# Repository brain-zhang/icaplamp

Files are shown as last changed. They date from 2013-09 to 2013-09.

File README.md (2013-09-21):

icaplamp
========

信息化矿灯

-------------------------------------------
这是朋友提议的一个想法。想要对传统的矿灯做些增强，实现考勤+信息接收+井下定位的功能;
根据这个想法做了个原型，实现了通信的功能(软硬件),定位及考勤功能开发了一个雏形。

    考勤:现实中矿上的考勤方式五花八门，从传统的科室登记，早班专人登记，取灯登记到人脸识别，虹膜识别等等，
    效果都不尽人意.....占用精力，代打卡也不能完全防止，机器识别精度差......

    井下电话:固话及小灵通通信方式倒是很可靠的，只是还不能人手一部。一般每个科室只能配几个。

    井下定位:只能说现有的所有井下定位都不靠谱，RFID定位方式不能适应井下复杂的环境，可靠性太低。

    矿灯是下井必备品，如果矿灯能兼具考勤+通信+定位的功能就比较方便了。
    我们希望通过在矿灯头部设计芯片，加挂贴片无线模块及LED显示屏的方式，实现这些功能。

    这种设计的可靠性，精度及实用性都有待检验，试做的时候碰到了许多问题，
    电池容量，AP功率，接收范围，LED体积，成本......但毕竟是一种思路。

    现在再看看，有些问题已经可以解决了，出现了更轻型更大容量的锂电，更低功耗的贴片天线，
    市面上也有了一些同类产品，但不知道效果如何；但解决成本及可靠性的问题，可能还要等很长时间......

    还有一些根本上的缺陷，功能太杂，很难简单操作，AP无线定位的精度太低，
    另外商业上看这种产品的亮点也不多，最后这种产品要想做成熟的话开发工作浩大......

    如果说有什么收获，可能就是学会了从电路设计,画PCP板子到出板子的一系列过程，
    知道了常用电子原件的价格，熟悉了MSP430的特性.....

    放在这里仅仅是记录曾经一段时间的工作吧。
    如果有人有兴趣翻一下的话，推荐你看下PCB的设计及keil的C程序，我认为这部分写得很清晰，对初学者有些价值。

-------------------------------------------
原理图

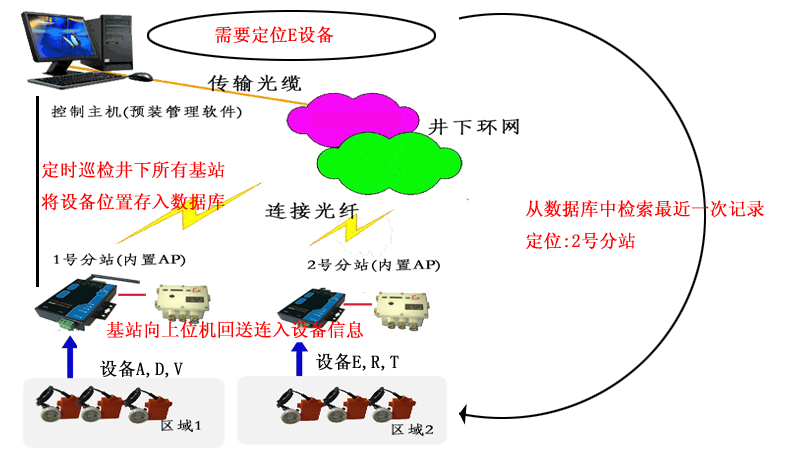
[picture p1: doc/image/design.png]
设计图


-------------------------------------------
电路图

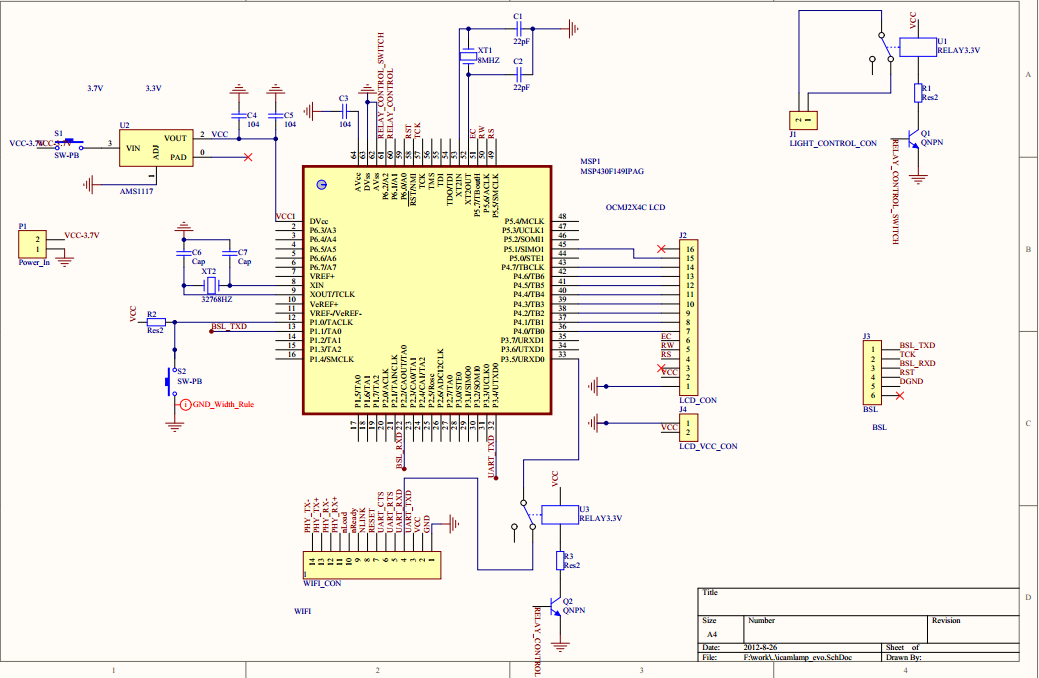
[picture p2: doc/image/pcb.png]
原理图

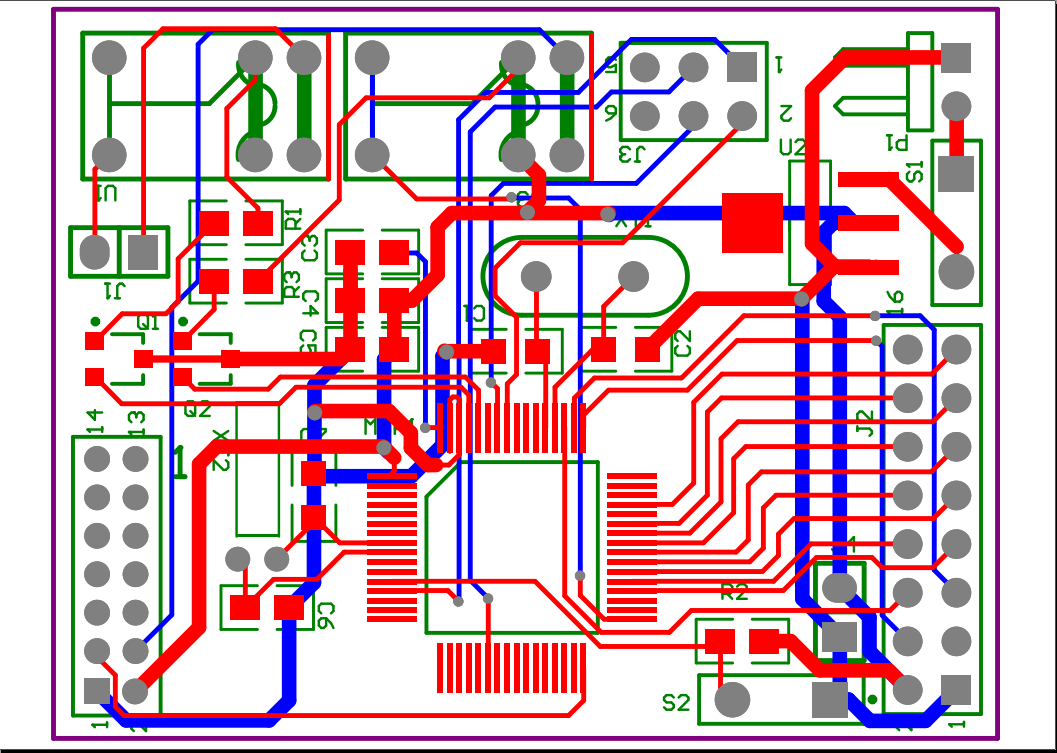
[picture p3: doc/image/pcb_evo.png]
布线图


-------------------------------------------
Resource

    |-- 3part                              第三方元件库
    |-- doc                                设计文档
    |   `-- image
    |-- hardware
    |   |-- PCBlib                         protel设计图
    |   |   `-- History
    |   |-- pcb
    |   `-- source                         keil MSP430程序
    |       |-- Debug
    |       |   |-- Exe
    |       |   |-- List
    |       |   `-- Obj
    |       `-- settings
    |-- software                           vs2010 Demo
    |   `-- IcapLamp
    |       |-- 3rddll
    |       |-- 3rdinclude
    |       |   |-- libssh2
    |       |   `-- openssl
    |       |-- 3rdlib
    |       |-- IcapLamp
    |       |   |-- CustomUtil
    |       |   |-- libssh2
    |       |   `-- res
    |       |-- IcapLampbase
    |       |   `-- IcapLampbase
    |       |       `-- Release
    |       |-- Release
    |       |-- ini
    |       `-- setup
    `-- test

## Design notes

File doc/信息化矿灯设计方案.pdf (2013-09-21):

# 信息化矿灯设计方案

## 一、功能

## 信息接收系统

通过在矿灯上加装信息化模块来接收无线基站的信号并且通过液晶屏幕显示，调度室可

以通过管理软件选择给某个工人单发信息或者给所有工人群发信息，工人的矿灯接收到信息

后头灯会有节奏的闪烁，提示有新信息，当工人阅读后按一下确认按键头灯停止闪烁。

## 人员定位系统

通过矿灯的无线接收模块，井下基站，配合上位机软件，实现人员定位功能：

A. 井上可实时显示基站覆盖范围内的所有矿灯设备
B. 井上可实时显示矿灯设备的井下位置
C. 井上可查询所有下井矿灯设备的位置移动历史记录，并可报表输出

## 二、系统结构

整个系统由无线基站、隔爆兼本安不间断电源、WIFI 模块、核心控制板、液晶屏、矿灯

等部分组成。

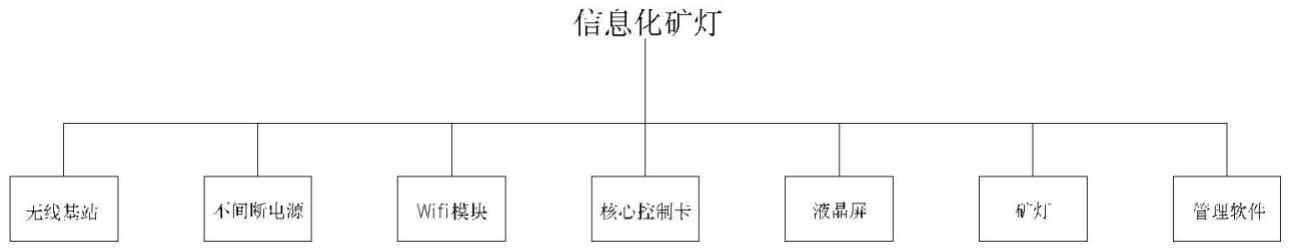
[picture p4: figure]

系统结构图

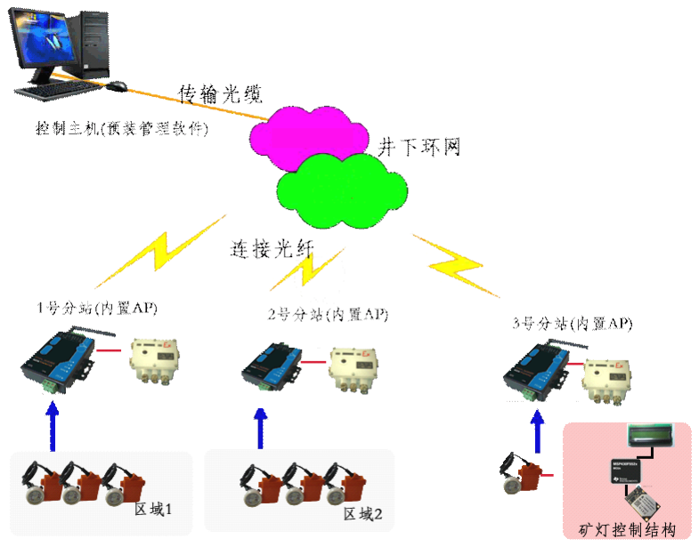
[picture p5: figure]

系统整体示意图

## 三、系统实现

信息接收及人员定位系统，主要依赖上位机软件及矿灯核心控制卡模块 PLC 程序配合完

成。

## 信息接收系统

矿灯设备通过基站接入环网后，WIFI 模块实现了串口设备的网络透明接入，因此可直接

利用 TCP/IP 实现网络通信模型。

核心控制卡 PLC 实现：

设定设备唯一标识(IP 地址)，响应上位机巡检指令

循环检测串口，接收上位机发送的消息，并显示在液晶屏上。

上位机软件实现：

巡检所有井下矿灯设备，并通过 IP 地址确定设备位置，进行如下操作：

1. 给某个工人单发信息
2. 给某组工人群发信息(所有设备群发可视为并入一组)

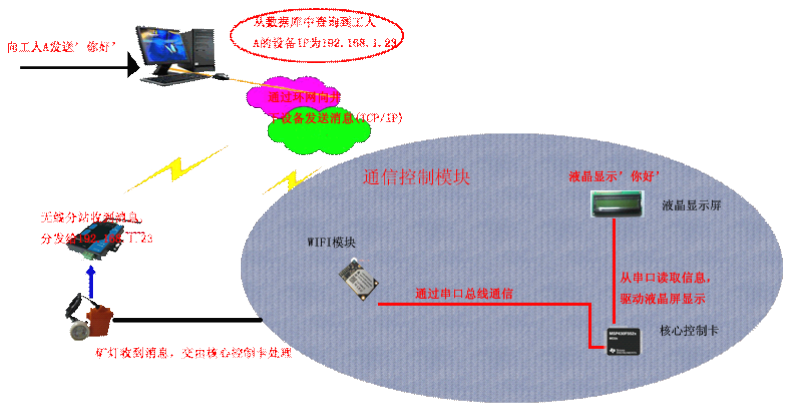
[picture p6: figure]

信息接收流程图

## 人员定位系统

矿灯设备接入井下环网后，可通过巡检每个基站的在线设备 IP 实现人员定位。

上位机软件实现：

1. 定时巡检井下基站(可设置间隔时间，建议 5-10 秒)，检测此基站范围内的所有设

备(通过 IP 地址识别)，并存入数据库。

2. 实时显示所有井下设备的位置信息。
3. 从数据库中查询某设备指定时间的位置记录。
4. 人员定位精度依赖基站的信号覆盖范围，大概 500 米误差。
5. 人员离开基站覆盖范围后，可查询此人员最近一次位置记录点。

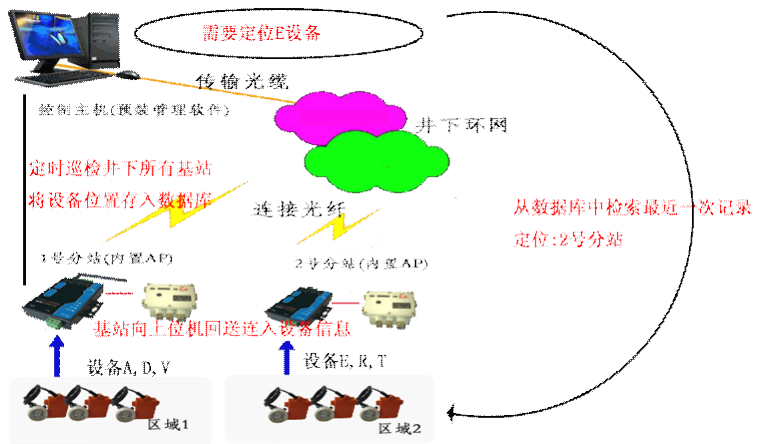
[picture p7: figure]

人员定位系统示意图

## 四、设备技术参数

## 1. 无线基站

无线基站的主要部件是大功率无线 AP，可视范围内覆盖范围可达 500 米。

处理器 | Atheros | MIPS | 24KC, | 400MHz
内存 | 64MB | SDRAM, | 8MB | Flash
网络接口 | 2 X 10/100 BASE-TX (Cat. 5, RJ-45) Ethernet Interface
天线接口 | 2x | RPSMA | (Waterproof)
电源 | 24V, | 1A | POE | Supply | Included
工作温度 | -30C | to | 75C
工作湿度 | 5 | to | 95% | Condensing
发射功率 | 650mW

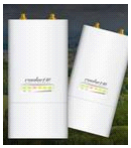
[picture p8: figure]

大功率无线 AP

此外，无线基站内还有矿用光电一体交换机，安装到现场后通过光纤将各基站连接到一

起。

## 2. 矿用隔爆兼本安不间断电源

采用隔爆兼本安不间断电源，正常情况下采用照明线路供电，井下停电时，自动切换到

蓄电池供电模式，保证系统的正常运行，提高系统可靠性。

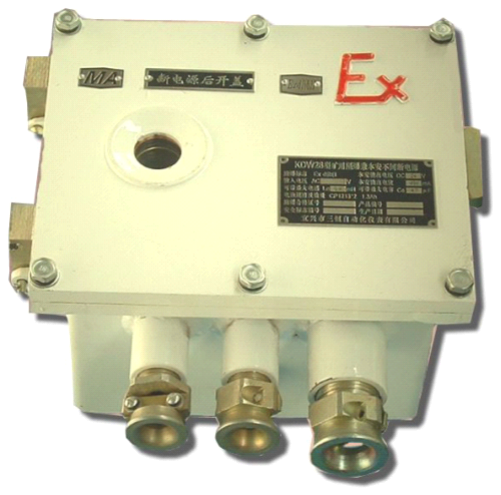
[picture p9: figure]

隔爆兼本安不间断电源

输入电压 | AC127V/380V/660V
工作温度 | -25C | to | 60C
工作时间 | ≥2小时(在额定电流时)
充电方式 | 内部浮充
标称输出电压 | DC | 18V
额定输出电流 | 250mA
最大短路电流 | ≤100mA

### 3. WIFI 模块

选用嵌入式 wifi 转串口模块，接收上位机的消息信号(标准 TCP/IP 协议传输)，转换为串

口数据通信，供核心控制卡处理。

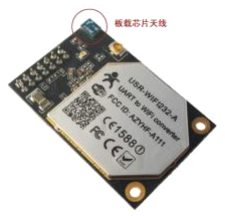
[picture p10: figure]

WIFI 转串口模块 内置天线

## 4. 核心控制卡

采用单片机(MSP430)定制开发，接收串口数据，显示到液晶屏上。

特点：

a. 处理能力强
b. 超低功耗
c. 片内资源丰富
无线标准 | 802.11n
串口命令 | AT+命令结构
数据接口 | URAT、以太网、GPIOs
天线 | 内置板载天线
电源 | 3.3v | 170mA-300mA
工作温度 | -10C | to | 70C
尺寸 | 30 | X | 45 | X | 8 | (mm)
接收灵敏度 | 802.11n:-71dbm

d. 方便高效的开发环境

核心控制卡集成了 wifi 模块，液晶屏及 LED 警示灯，与上位机通过无线网络进行消息传

递，是整套系统井下部分的核心。

## 5. 液晶屏

系统采用 1602 字符型液晶显示，具有功耗低，显示文字锐利，体积小，重量轻的优点。

特性：

a. +5V 电压，对比度可调
b. 内含复位电路
c. 提供各种控制命令,如：清屏、字符闪烁、光标闪烁、显示移位等多种功能
d. 有 80 字节显示数据存储器 DDRAM
e. 内建有 192 个 5X7 点阵的字型的字符发生器 CGROM
f. 8 个可由用户自定义的 5X7 的字符发生器 CGRAM

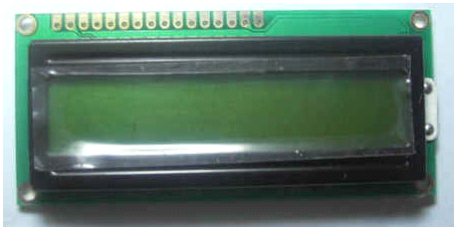
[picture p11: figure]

1602 字符型液晶实物图

## 6. 矿灯

改造模具，在原有产品基础上进行集成。

## 7. 管理软件

井上部分提供控制软件。功能描述如下：

a) 信息接收系统

1. 向井下矿灯设备发送消息
2. 向某一区域矿灯设备发送消息
3. 巡检某一区域(或全体)在线矿灯设备
b) 人员定位系统
4. 实时显示基站覆盖范围内的所有矿灯设备
5. 实时显示所有矿灯设备的井下位置
6. 查询某一基站范围内的矿灯设备历史记录，并可报表输出
7. 查询下井矿灯设备的位置移动历史记录，并可报表输出

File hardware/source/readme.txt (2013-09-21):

2012-08-15
加入了消息存储的底层函数支持。
2012-08-19
基本功能完成，还有按键处理待修改。

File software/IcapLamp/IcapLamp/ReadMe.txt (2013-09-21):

================================================================================
MICROSOFT 基础类库: IcapLamp 项目概述
===============================================================================

应用程序向导已为您创建了这个 IcapLamp 应用程序。此应用程序不仅演示 Microsoft 基础类的基本使用方法，还可作为您编写应用程序的起点。

本文件概要介绍组成 IcapLamp 应用程序的每个文件的内容。

IcapLamp.vcxproj
这是使用应用程序向导生成的 VC++ 项目的主项目文件。 
它包含生成该文件的 Visual C++ 的版本信息，以及有关使用应用程序向导选择的平台、配置和项目功能的信息。

IcapLamp.vcxproj.filters
    这是使用“应用程序向导”生成的 VC++ 项目筛选器文件。
    它包含有关项目文件与筛选器之间的关联信息。在 IDE 中，通过这种关联，在特定节点下以分组形式显示具有相似扩展名的文件。例如，“.cpp”文件与“源文件”筛选器关联。

IcapLamp.h
这是应用程序的主要头文件。它包括其他项目特定的头文件(包括 Resource.h)，并声明 CIcapLampApp 应用程序类。

IcapLamp.cpp
这是包含应用程序类 CIcapLampApp 的主要应用程序源文件。

IcapLamp.rc
这是程序使用的所有 Microsoft Windows 资源的列表。它包括 RES 子目录中存储的图标、位图和光标。此文件可以直接在 Microsoft Visual C++ 中进行编辑。项目资源位于 2052 中。

res\IcapLamp.ico
这是用作应用程序图标的图标文件。此图标包括在主要资源文件 IcapLamp.rc 中。

res\IcapLamp.rc2
此文件包含不在 Microsoft Visual C++ 中进行编辑的资源。您应该将不可由资源编辑器编辑的所有资源放在此文件中。

/////////////////////////////////////////////////////////////////////////////

对于主框架窗口:
项目包含标准 MFC 界面。

MainFrm.h, MainFrm.cpp
这些文件包含框架类 CMainFrame，该类派生自
CFrameWnd 并控制所有 SDI 框架功能。

/////////////////////////////////////////////////////////////////////////////

应用程序向导创建一个文档类型和一个视图:

DirectionMonitorDoc.h，IcapLampDoc.cpp - 文档
这些文件包含 CDirectionMonitorDoc 类。编辑这些文件可以添加特殊文档数据并可实现文件保存和加载(通过 CDirectionMonitorDoc::Serialize)。

DirectionMonitorFormView.h，IcapLampView.cpp - 文档的视图
这些文件包含 CDirectionMonitorFormView 类。
CDirectionMonitorFormView 对象用于查看 CDirectionMonitorDoc 对象。

/////////////////////////////////////////////////////////////////////////////

其他功能:

ActiveX 控件
应用程序包括对使用 ActiveX 控件的支持。

打印及打印预览支持
应用程序向导已通过从 MFC 库调用 CView 类中的成员函数，生成了用于处理打印、打印设置和打印预览命令的代码。

Windows Sockets
应用程序支持通过 TCP/IP 网络建立通信。

/////////////////////////////////////////////////////////////////////////////

其他标准文件:

StdAfx.h，StdAfx.cpp
这些文件用于生成名为 IcapLamp.pch 的预编译头 (PCH) 文件和名为 StdAfx.obj 的预编译类型文件。

Resource.h
这是标准头文件，它定义新的资源 ID。
Microsoft Visual C++ 读取并更新此文件。

IcapLamp.manifest
	应用程序清单文件供 Windows XP 用来描述应用程序
	对特定版本并行程序集的依赖性。加载程序使用此
	信息从程序集缓存加载适当的程序集或
	从应用程序加载私有信息。应用程序清单可能为了重新分发而作为
	与应用程序可执行文件安装在相同文件夹中的外部 .manifest 文件包括，
	也可能以资源的形式包括在该可执行文件中。 
/////////////////////////////////////////////////////////////////////////////

其他注释:

应用程序向导使用“TODO:”指示应添加或自定义的源代码部分。

如果应用程序在共享的 DLL 中使用 MFC，则需要重新发布这些 MFC DLL；如果应用程序所用的语言与操作系统的当前区域设置不同，则还需要重新发布对应的本地化资源 MFC100XXX.DLL。有关这两个主题的更多信息，请参见 MSDN 文档中有关 Redistributing Visual C++ applications (重新发布 Visual C++ 应用程序)的章节。

/////////////////////////////////////////////////////////////////////////////

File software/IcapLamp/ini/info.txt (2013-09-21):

信息化矿灯在线监控系统(Demo Beta1.0)  用于演示
memoryboxes@gmail.com

程序采用了libssh2、easySqlite等多方开源库。

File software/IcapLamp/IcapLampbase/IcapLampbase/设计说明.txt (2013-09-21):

MineIcapLampBase作为IcapLamp的底层类库实现。
思路是界面和功能分离。IcapLamp作为GUI单独实现，目前采用的MFC(vs2010的MFC版本中包含控件比较丰富)自定义浮动的风格样式工程。
MineIcapLampBase由以下部分组成。

MIL_BaseObject:
	作为所有操作的基类，封装了序列化及状态报告两个功能。

MIL_Exception:
	为工程提供异常封装，因为异常信息比较简单，没有采用类层次封装，仅仅在内部定义了用到的异常类型。

MIL_Database:
	采用soci C++数据访问库，在此基础上提供了本系统所有的数据库操作。
	后端数据库可以采用Mysql、postgresql、sqlite或是使用ODBC访问MS SQLServer。目前测试的时候使用sqlite3，生产环境使用postgresql。
	需要注意的是，切换数据库时，需要重新生成soci的lib文件，具体参见soci的文档。

MIL_Reporter:
	提供Log及报警功能，大部分Log是捕获MIL_Exception后过滤到MIL_Reporter处理。

MIL_Communicate:
	提供对矿灯的数据收发功能。

MIL_Lamp:
	封装了矿灯的操作。

MIL_Worker:
	封装了工人常用信息，一个MIL_Worker会持有MIL_Lamp Object。

MIL_WorkersManage:
	对一组工人进行操作，例如获取当前在井下的工人，获取在A点活动的工人等等..

MIL_AllWorkersManage:
	持有MIL_WorkersManage，生命期一直持续与整个系统，载入所有工人信息(井下活动人员、井上工作人员、人员删减、人员考勤等等)，其中的load()功能
	用于载入所有当前工人信息，另外要考虑程序意外终止的情况。

MIL_StationManage:
	封装了基站的操作。
	其中会启动后台线程定期扫描基站，采用观察者模式与MIL_AllWorkersManage通信，维护工人状态。

采用的第三方库有:
boost_1_42_0
soci3.1.0
sqlite3
libssh2-1.4.2

其中 boost及soci及sqlite3的库目录在d:\backup\vslib\
其他库目录在f:\work\信息化矿灯\software\IcapLamp\3rdinclude\ 及 f:\work\信息化矿灯\software\IcapLamp\3rdlib\

其中soci切换数据库支持时需要重新编译，编译时也要注意debug及release的区别。

boost库不需单独编译，但编写代码时要打开宏开关BOOST_ALL_NO_LIB

编译时线程选项为MT/MTD，注意工程和库的编译保持一致。

以上类会封转大部分涉及到定位的功能，另外也会涉及少部分的考勤功能。
报表、图形化显示部分是独立的，可以拆分出来另外设计，不会影响以上类的实现。

大量采用STL及boost组件，要求你熟悉C++ 泛型编程。

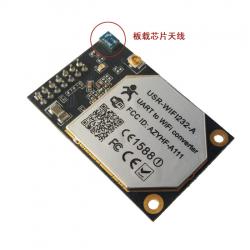
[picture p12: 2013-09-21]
doc/image/串口转wifi.jpg

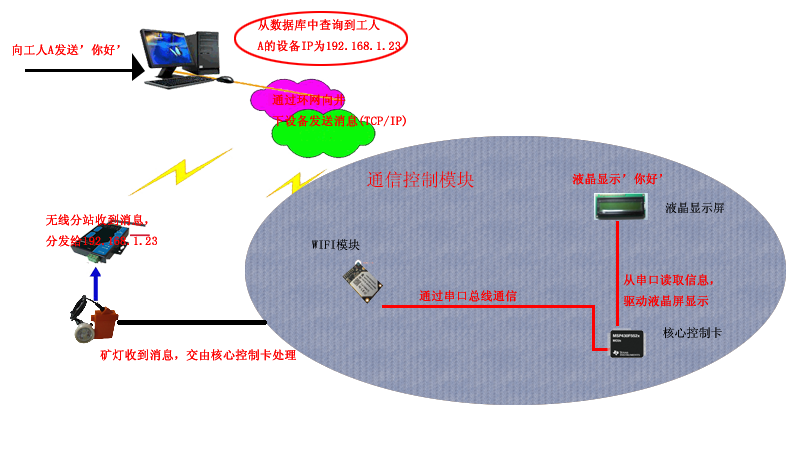
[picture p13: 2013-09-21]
doc/image/信息接收系统示意图.png

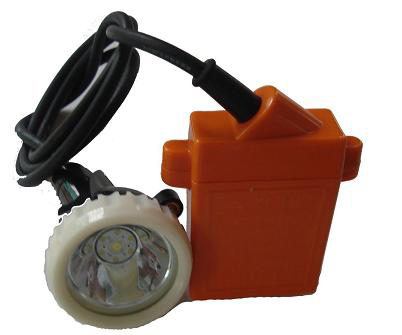
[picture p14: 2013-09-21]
doc/image/矿灯.jpg

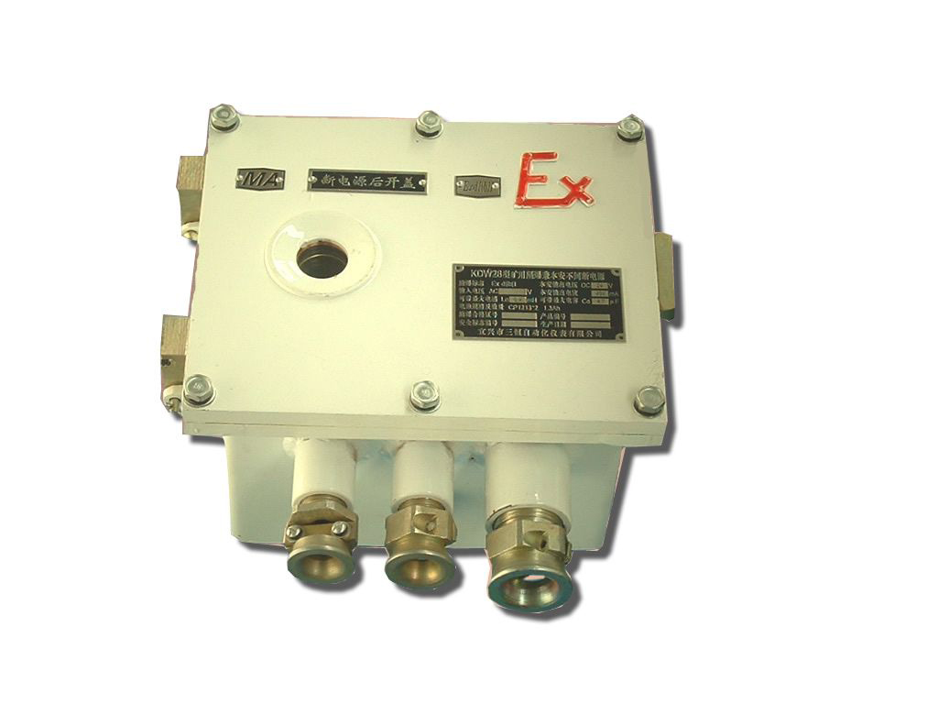
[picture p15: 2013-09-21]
doc/image/隔爆兼本安不间断电源.jpg

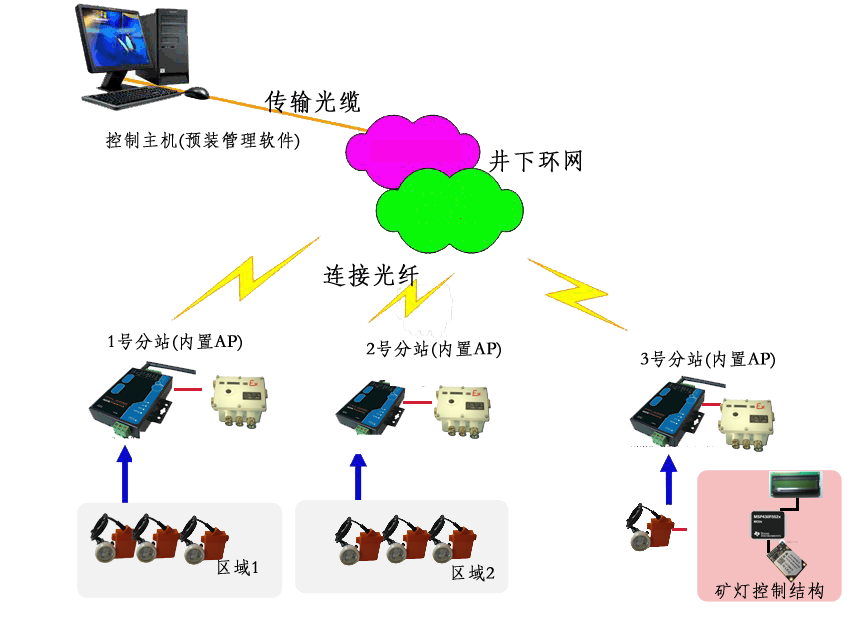
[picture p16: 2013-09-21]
doc/image/总体架构.png

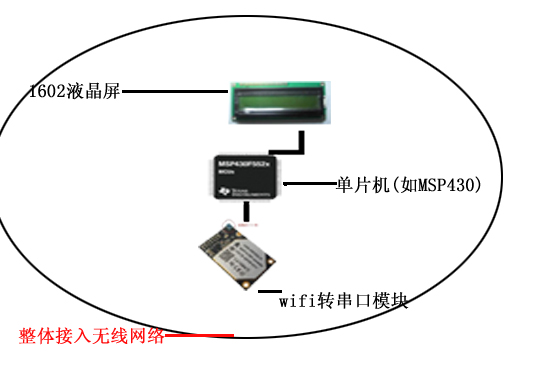
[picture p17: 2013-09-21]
doc/image/矿灯结构 拷贝.jpg

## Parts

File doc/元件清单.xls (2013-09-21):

信息矿灯模块矿灯元件清单
元件名 | 元件型号 | 数量
电容 | 104,"0805","3","C3, C4, C5","Capacitor" | 3
电容 | 22pF,"0805","4","C1, C2，C6，C7","Capacitor" | 4
晶振 | 32768HZ,"AT26","1","XT2","CY-AT26-32768HZ" | 1
晶振 | 8MHZ,"HC-49S","1","XT1","CY-49S-8MHZ" | 1
电源稳压模块 | AMS1117,"SOT-223","1","U2","LDO ADJ" | 1
BSL下载设备 | BSL,"HDR2X3","1","J3","" | 1
液晶屏 | LCD_CON,"OCMJ2X4C","1","J2","" | 1
CPU | MSP430F149IPAG,"PAG","1","MSP1","MSP430F149IPAG" | 1
电源开关 | Power_In,"HDR1X2H","1","P1","Header, 2-Pin, Right Angle" | 1
三极管 | QNPN,"SO-G3/C2.5","2","Q1, Q2","NPN Bipolar Transistor" | 2
继电器 | RELAY3.3V,"Relay5V" OMRON G5V-1,"2","U1, U3","" | 2
电阻 | Res2,"0805","3","R1, R2, R3","Resistor" | 3
按键 | SW-PB,"SPST-2","2","S1, S2","Switch" | 2
无线通信模块 | WIFI_CON,"USR-WIFI232-x-V3.1","1","1","" | 1
信息矿灯分站器件清单
器件名称 | 型号 | 数量
AP | UBNT RocketM2 | 1
工业以太网交换机 | 迈威光电一体 | 1
光线终端盒 |  | 1
防爆外壳 |  | 1
电源器件清单
器件名称 | 型号 | 数量
锂电池 | 20000mah | 1
控制卡 | 迈威光电一体 | 1
防爆外壳 |  | 1

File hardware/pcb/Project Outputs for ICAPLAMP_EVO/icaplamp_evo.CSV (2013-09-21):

Bill of Material for icaplamp_evo.PcbDoc
On 2012-9-2 at 20:17:12
Comment | Pattern | Quantity | Components
104 | 0805 | 3 | C3, C4, C5 | Capacitor
22pF | 0805 | 2 | C1, C2 | Capacitor
32768HZ | AT26 | 1 | XT2 | CY-AT26-32768HZ
8MHZ | HC-49S | 1 | XT1 | CY-49S-8MHZ
AMS1117 | SOT-223 | 1 | U2 | LDO ADJ
BSL | HDR2X3 | 1 | J3
Cap | 0805 | 2 | C6, C7 | Capacitor
LCD_CON | HDR2X8 | 1 | J2
LCD_VCC_CON | SIP2 | 1 | J4
LIGHT_CONTROL_CON | SIP2 | 1 | J1
MSP430F149IPAG | PAG | 1 | MSP1 | MSP430F149IPAG
Power_In | HDR1X2H | 1 | P1 | Header, 2-Pin, Right Angle
QNPN | SO-G3/C2.5 | 2 | Q1, Q2 | NPN Bipolar Transistor
RELAY3.3V | Relay5V | 2 | U1, U3
Res2 | 0805 | 3 | R1, R2, R3 | Resistor
SW-PB | SPST-2 | 2 | S1, S2 | Switch
WIFI_CON | wificon | 1 | 1

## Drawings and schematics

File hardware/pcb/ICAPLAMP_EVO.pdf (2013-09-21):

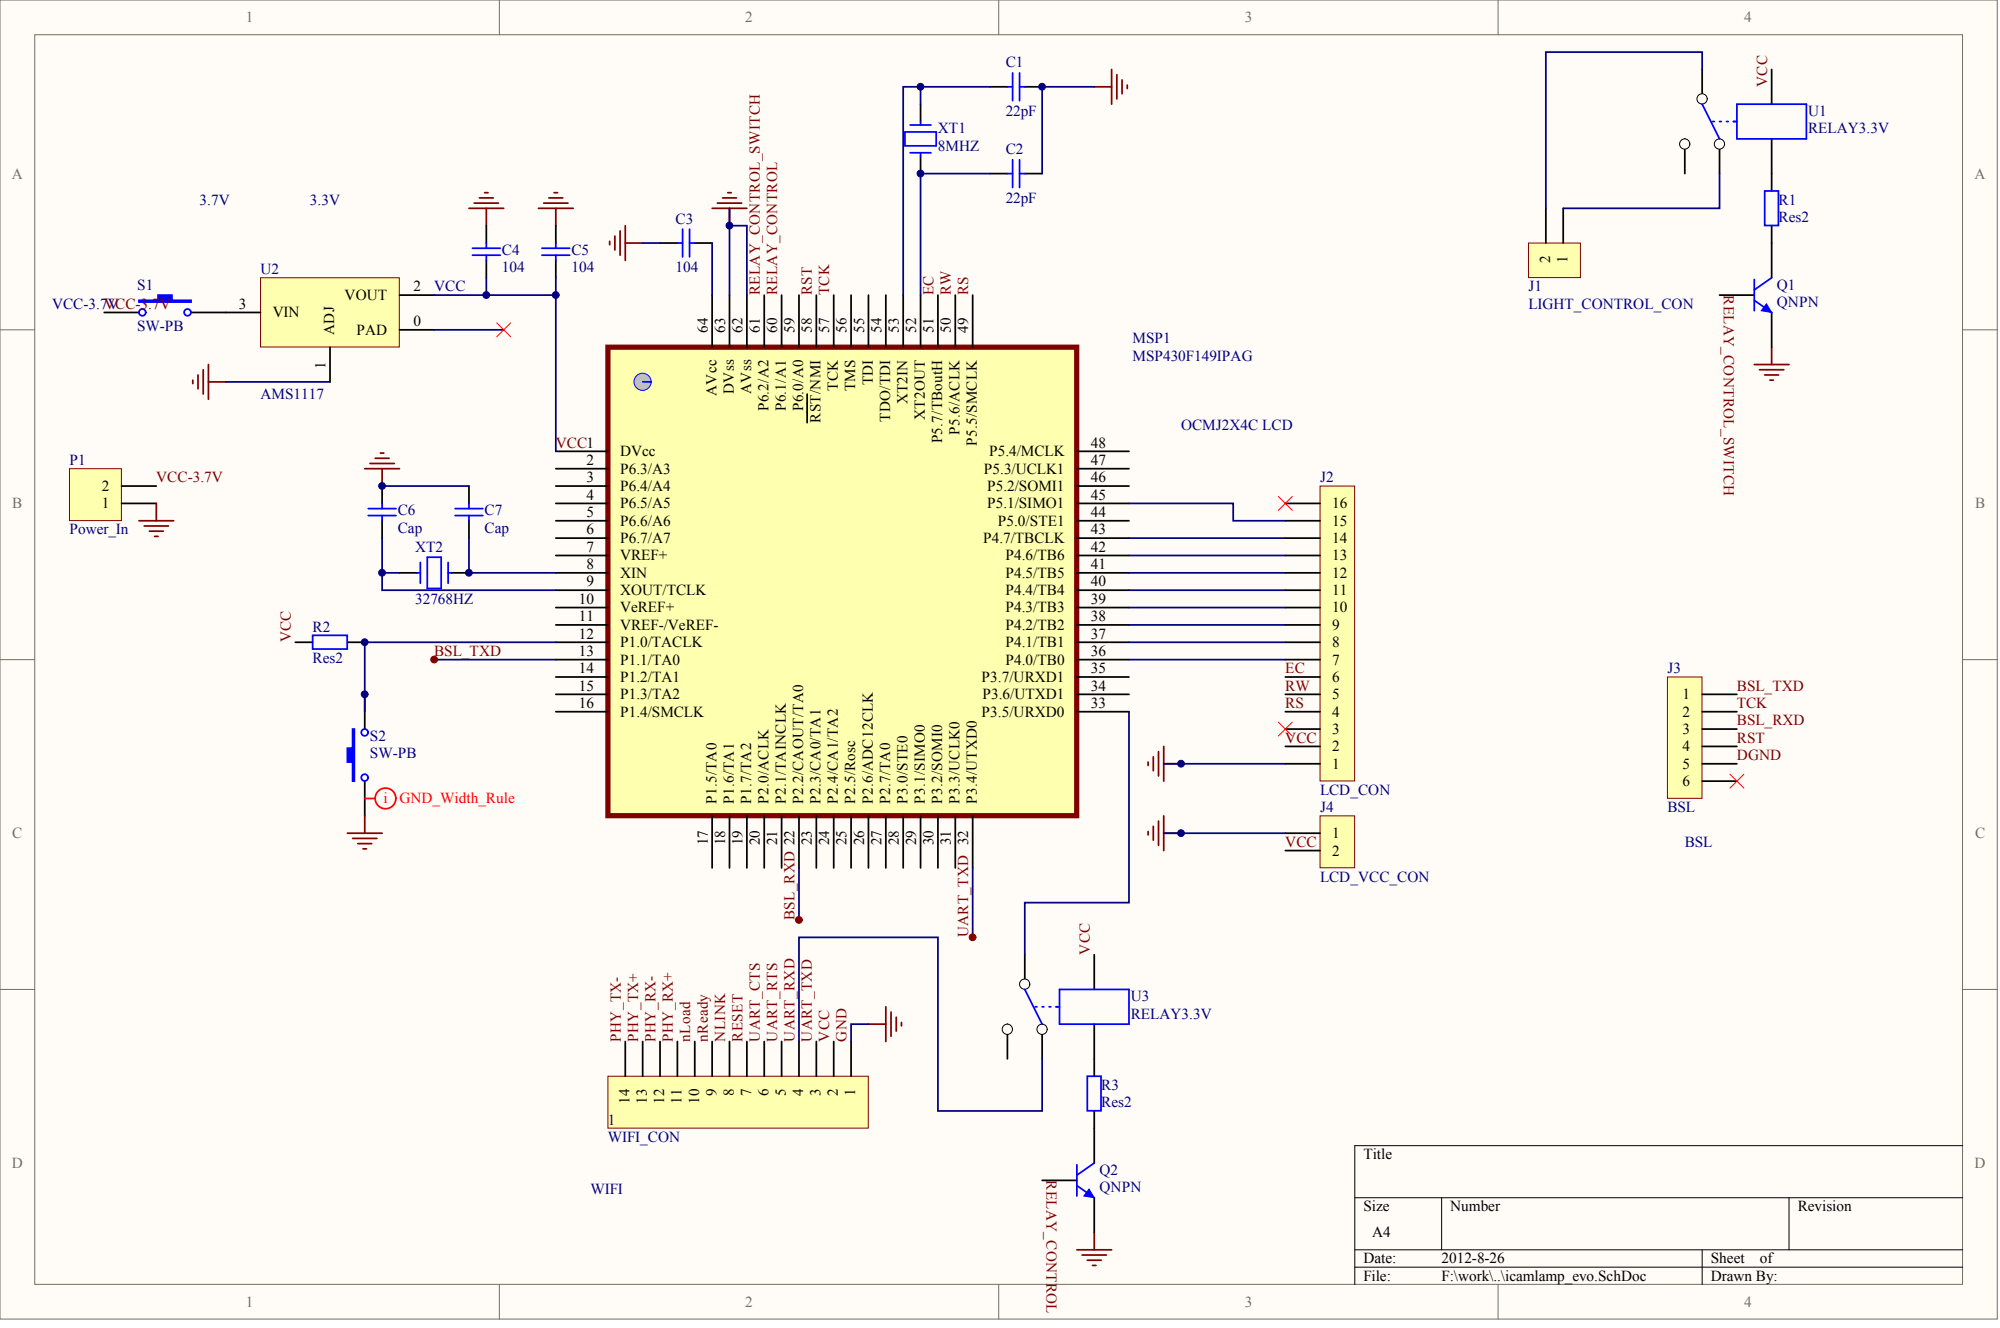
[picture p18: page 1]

P5.5/SMCLK 49 P5.6/ACLK 50 P5.7/TBoutH 51 XT2OUT 52 XT2IN 53 TDO/TDI 54 TDI 55 TMS 56 TCK 57 RST/NMI 58 P6.0/A0 59 P6.1/A1 60 P6.2/A2 61 AVss 62 DVss 63 AVcc 64

XT2 | | 7 P0MSP108 P0XT201 P0MSP108 P0XT201 | | P0J2013 P0J2013 P0J2013

8 P0MSP108 | | P0J2012 P0J2012 P0J2012
9 | | P0J2011 P0J2011 P0J2011

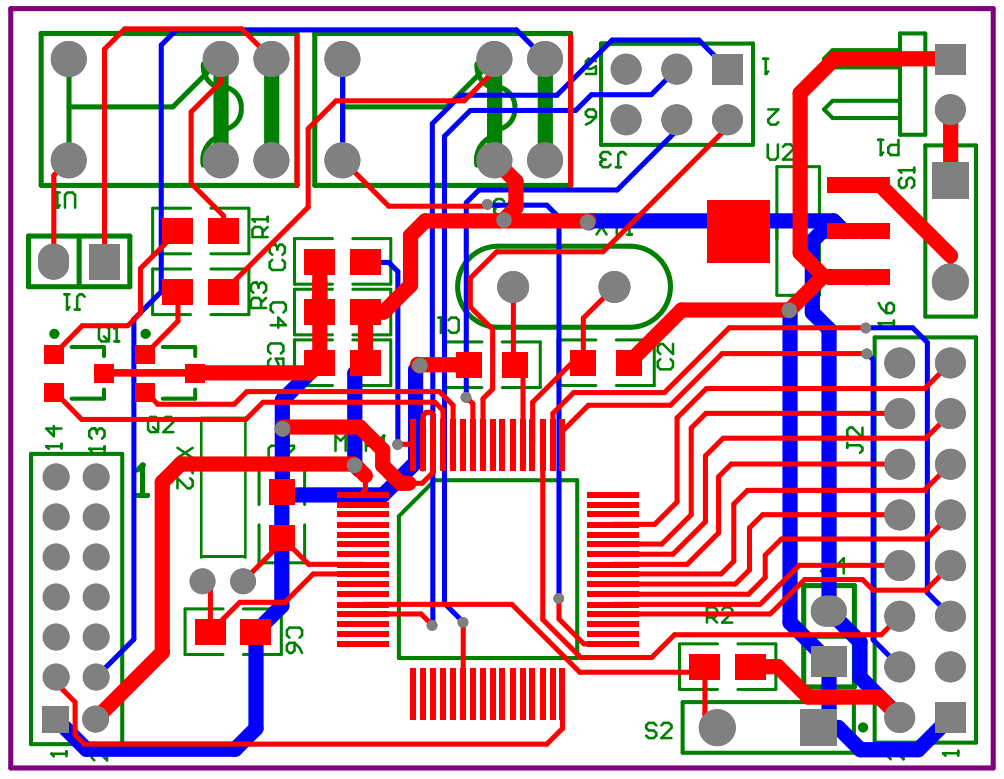
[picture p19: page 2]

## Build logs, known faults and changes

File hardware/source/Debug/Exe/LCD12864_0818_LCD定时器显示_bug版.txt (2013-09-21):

@1100
D0 C0 CA C0 BC CD B5 E7 D7 D3 BB B6 D3 AD C4 E3
00 CD FA 3A 6A 69 6E 67 79 65 68 61 6E 78 69 6E
67 00 77 77 77 2E 61 76 72 67 63 63 2E 63 6F 6D
20 20 00 B5 E7 BB B0 30 35 37 34 38 37 34 37 36
38 37 30 00 31 40 00 0A B0 12 44 12 B0 12 E2 12
7C 40 30 00 B0 12 6C 12 00 3C 3F 40 13 34 3F 53
FE 2F 7C 40 30 00 B0 12 6C 12 00 3C 3F 40 13 34
3F 53 FE 2F 7C 40 0C 00 B0 12 6C 12 00 3C 3F 40
13 34 3F 53 FE 2F 5C 43 B0 12 6C 12 00 3C 3F 40
13 34 3F 53 FE 2F 30 41 3D 40 00 11 7C 40 80 00
B0 12 F2 11 3D 40 11 11 7C 40 88 00 B0 12 F2 11
3D 40 22 11 7C 40 90 00 B0 12 F2 11 3D 40 33 11
7C 40 98 00 30 40 F2 11 F2 C0 80 00 57 00 F2 D0
88 00 58 00 E2 C3 02 00 4E 43 02 3C 03 43 5E 53
7E 90 64 00 FB 2B E2 B3 02 00 F4 2F E2 C3 02 00
30 41 B0 12 6C 12 00 3C 3F 40 13 34 3F 53 FE 2F
09 3C 6C 4D B0 12 1C 12 1D 53 00 3C 3F 40 13 34
3F 53 FE 2F CD 93 00 00 F4 23 30 41 F2 D0 20 00
31 00 F2 C0 40 00 31 00 F2 D0 80 00 31 00 C2 4C
1D 00 00 3C 3F 40 13 34 3F 53 FE 2F F2 C0 80 00
31 00 30 41 B0 12 D6 12 B0 12 C8 11 B0 12 94 12
3F 40 3E 0D 3E 40 03 00 3F 53 3E 63 FD 2F B0 12
50 11 B0 12 C4 12 B0 12 98 11 FD 3F F2 C0 20 00
31 00 F2 C0 40 00 31 00 F2 D0 80 00 31 00 C2 4C
1D 00 00 3C 3F 40 13 34 3F 53 FE 2F F2 C0 80 00
31 00 30 41 C2 43 1F 00 F2 43 1E 00 C2 43 33 00
F2 D0 E3 00 32 00 D2 D3 31 00 E2 D3 31 00 30 41
0A 12 21 83 0A 4C 81 4A 00 00 0D 41 5C 43 B0 12
E6 12 F9 3F 5C 43 B0 12 6C 12 00 3C 3F 40 13 34
3F 53 FE 2F 30 41 B2 40 80 5A 20 01 30 41 30 40
B0 12 30 40 DE 12 30 41 
@FFFE
44 11 
q

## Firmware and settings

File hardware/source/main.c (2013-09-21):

#include "hardware.h"
#include "lcd.h"
#include "com.h"
#include "msg.h"
#include "flash.h"
#include "key.h"
#include "wifi.h"

void OnError()
{
  LCD_debug_displayCgrom("Error,Not enough memory");
}

void Test()
{
  //FLASH_test();
  //LCD_test();
  //WIFI_test();
  KEY_test();
}

void InitSysEnv()
{
  //初始化时钟、端口、看门狗
  WDT_init(); 
  Clock_init(); 
  Port_init();
  
  //键盘控制初始化
  KEY_init();
  
  //初始化URAT控制口
  UART_init();
  
  //初始化Flash存储
  FLASH_init_ini();
  
  //wifi连接初始化
  WIFI_init();
  
  void Spark_init();
}

void InitGraphic()
{
  //初始化图形环境
  LCD_initial();
  
  //清屏
  LCD_cls();
}

void main(void)
{
  InitSysEnv();
  
  InitGraphic();
  
  MSG_init();
  
  //Test();
  
  Msg message;
  
  while(1)
  {
    message = MSG_getMessage();
    MSG_dealMessage(&message);
  }
}

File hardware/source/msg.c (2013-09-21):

#include "hardware.h"
#include "msg.h"
#include "com.h"
#include "lcd.h"
#include "flash.h"
#include "key.h"
#include "menu.h"
#include "signal.h"
#include "spark.h"

#define MAX_MSG_COUNT 5
#define MESSAGE_RESPONSE_SEG SIG_RESPONSE_SEG

#define MESSAGE_WELCOME_STRING "安全生产平安回家"
#define MESSAGE_RESPONSE_STRING "已发出回应信息"

/***********要求简单，一个消息队列，如果消息个数超出限制，冲掉最旧的消息****************/
static Msg message_queue[MAX_MSG_COUNT];
static uchar message_head = 0;
static uchar message_tail = 0;
static uchar message_is_full_tag = 0;

//*************************************************************************
//                        消息入队
//*************************************************************************
static void msg_en_queue(const Msg* message)
{
  message_queue[message_tail] = *message;
  if((message_head == message_tail) && message_is_full_tag)
  {
    //此时队列满，冲掉最旧的消息
    message_tail = (message_tail + 1) % MAX_MSG_COUNT;
    message_head = (message_head + 1) % MAX_MSG_COUNT;
  }
  else
  {
    //正常情况
    message_tail = (message_tail + 1) % MAX_MSG_COUNT;
    if(message_head == message_tail)
    {
       //此时队列满
      message_is_full_tag = 1;
    }
  }
}

//*************************************************************************
//                        消息出队
//*************************************************************************
static Msg msg_de_queue()
{
  Msg r_message;
  if((message_head == message_tail) && !message_is_full_tag)
  {
    //此时队列为空
    r_message.msg_type = MESSAGETYPE_NONE;
  }
  else
  {
    r_message = message_queue[message_head];
    message_head = (message_head + 1) % MAX_MSG_COUNT;
    if(message_head == message_tail)
    {
      //此时队列为空
      message_is_full_tag = 0;
    }
  }
  return r_message;
}

//*************************************************************************
//                       设定显示消息延时时间
//*************************************************************************
static void msg_set_delay(Msg *message, uchar count)
{
  message->message.gui_message.gui_delay_value = count;
}

//=============================对外接口========================================

//*************************************************************************
//                        初始化消息模块
//*************************************************************************
void MSG_init()
{
  //发送一条描画消息，显示关机前看的最后一条记录
  //如果刚刚出厂初始化，则显示 "安全生产平安回家" 提示信息
  Msg temp_message;
  temp_message.msg_type = MESSAGETYPE_GUI;  
  if(FLASH_get_curr_record_count() > 0)
  {
    temp_message.message.gui_message.gui_type = MESSAGETYPE_GUI_SHOW_MESSAGE;
  }
  else
  {
    temp_message.message.gui_message.gui_type = MESSAGETYPE_GUI_SHOW_WELCOME;
  }
  msg_set_delay(&temp_message, 0);
  MSG_sendMessage(&temp_message);
}

//*************************************************************************
//                        发送消息
//*************************************************************************
void MSG_sendMessage(Msg *message)
{
    msg_en_queue(message);
}

//*************************************************************************
//                      主循环函数，接受数据并传送消息
//*************************************************************************
Msg MSG_getMessage()
{
    //扫描按键
    Msg key_message;
    uchar key = KEY_scan();
    if(key != KEY_VALUE_NULL)
    {
      //如果有按键处理，发送消息
      key_message.msg_type = MESSAGETYPE_KEY;
      key_message.message.key_message.key_value.ktat = key;
      msg_en_queue(&key_message);
    }
    
    return msg_de_queue();
}

//*************************************************************************
//                       处理消息
//*************************************************************************
void MSG_dealMessage(const Msg *message)
{
  Msg temp_message = *message;

  switch(temp_message.msg_type)
  {
  case MESSAGETYPE_COM:
    //如果有COM数据接收消息
    //可以插入自定义消息，根据页号及消息含义来进行相应处理，消息号请在开始时宏定义，请灵活使用
    //目前是从消息中取出串口数据，再发送一条界面重绘的消息
    temp_message.msg_type = MESSAGETYPE_GUI;  
    temp_message.message.gui_message.gui_type = MESSAGETYPE_GUI_SHOW_MESSAGE;
    msg_set_delay(&temp_message, 0);    
    MSG_sendMessage(&temp_message);
    
    //发送灯头闪烁的消息
    temp_message.msg_type = MESSAGETYPE_SYS_SPARK;  
    temp_message.message.sys_message.sys_value = SPARK_COUNT;
    temp_message.message.sys_message.sys_delay_value = SPARK_INTERVAL;
    MSG_sendMessage(&temp_message);
    
    break;
    
  case MESSAGETYPE_SYS_SPARK:
    //处理头灯闪烁
    if(temp_message.message.sys_message.sys_delay_value-- >1)
    {
      delay_ms(10);
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
